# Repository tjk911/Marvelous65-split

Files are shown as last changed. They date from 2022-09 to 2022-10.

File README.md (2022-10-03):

# Marvelous65 Split

All the credit goes to [karnadii](https://github.com/karnadii/marvelous65) for his initial work. This repo is primarily for my documentation purposes and as a guide for anyone that would like to build this but might be as inexperienced as I was when I attempted this. This contains only documentation and updates to the split layout.

Shoutout to [karnadii](https://github.com/karnadii), [Nicell](https://github.com/nicell), bravekarma and the other zmk and nice!nano discord folks that helped me get as far as I did.

## Differences from karnadii's original

I'm running nice!nano on my build instead of nrfmicro. 

If you're buildings his other layouts (marvelous65 and marvelous65-ergo), some of my changes might work there as well. YMMV.

- added nice_nano_v2.overlay, with changes to the mosi-pin
- added oled changes to marvelous_split.dtsi, a zmk change implemented [here](https://zmk.dev/blog/2022/04/02/zephyr-3-0#display-selection)
- updated marvelous65_split.dtsi to reverse flipped encoder

## Known issues
- [OLED issue](https://github.com/zmkfirmware/zmk/issues/674)
- [Split peripheral encoder](https://github.com/zmkfirmware/zmk/pull/728)
  - I pulled [infused-tree](https://github.com/infused-kim/zmk/tree/my-changes/split-encoder)'s changes pending it getting merged into ZMK. So far working OK as of 9/30/22.
- Case does not have access to reset button, or on/off switch toggle
- Seeming to have some lag between the left and the right side in terms of input, I type at a range of 90-130WPM depending on the day but I'm not sure if it's apparent for folks that type slower

## 1. Ordering your PCB

Much like his original repo - you'll have to order these PCBs off of a site like JLCPCB (reach out to me as I might have a few extras lying around). 

You can upload the Gerbers I included to JLCPCB (`Hardware/Gerbers/Gerbers.zip`) or generate them yourself from the Kicad project file.

Options I chose, many of them are default, but I'm including them here for anyone that might find it useful:
- Base material: FR-4
- Layers: 2
- Dimensions: 345.28 * 107.17 (this should be default)
- Panel Qty: 5 (this is the minimum)
- Product Type: Industrial/Consumer electronics
- Different design: 2 
  - This defaults to 1 but it's 2 as they're two separate boards
- Delivery Format: Panel by Customer
- PCB Thickness: 1.6
- PCB Color: Hey, you do you
- Silkscreen: White
- Silkscreen Technology: Ink-jet/Screen Printing Silkscreen
- Sufrace Finish: LeadFree HASL
- Outer Copper Weight: 1 oz
- Gold Fingers: No
- Confirm Production file: Yes
- Flying Probe Test: Fully Test
- Castellated Holes: No
- Remove Order Number: No

### PCB Assembly options

- PCBA Type: Standard
- Assembly Side: Both Sides 
  - I believe you only need the Bottom, but I opted not to risk it during my first build
- PCBA Qty: 5
- Edge Rails/Fiducials: Added by JLCPCB
- Confirm Parts Placement: Yes

After this, you'll need to upload a BOM file and a CPL file. These are `Marvelous65 Split-bom.csv` and `Marvelous65 Split-all-pos.csv` respectively.

You might have to confirm/review the parts. I've noticed that the LED (WS2812B) and the 3.5mm audio jack (PJ-320D) tends to fail to match. Do a search for it and select the appropriate one.

Double check your PCB, I had to rotate the headphone jack to be vertical.

Boom - you're good to go. Pay the good folks and while you're waiting impatiently for your PCBs, get ready to do more shopping.

## 2. Other things you're going to need

I'm assuming you already have a soldering kit etc. Note that while I'll link to the shop pages I bought from - there are no affiliate links whatsoever and I have **no** relationships with these stores. Feel free to shop around and get what serves you best.

For this keyboard specifically, you'll need at least:
- 2x [nice!nano v2s](https://typeractive.xyz/products/nice-nano)
- 2x Lithium batteries
  - You can go big(ger) and grab the [750mAh](https://typeractive.xyz/products/lithium-battery-750mah) batteries or the slimmer [110mAh](https://typeractive.xyz/products/lithium-battery-110mah) versions. 
  - I've heard tell that you can tuck the 110mAh batteries under the nice!nano itself, which might be nice if you're looking for a neat, compact internal
  - I opted for ones with JST sockets
- 2x [Machine sockets and pins](https://typeractive.xyz/products/nice-nano)
  - Technically a nice-to-have but this saved me from a screwup, and it's helpful to be able to unplug the board for troubleshooting
- 2x [128x32 OLED](https://smile.amazon.com/dp/B08ZY4YBHL)
  - Note: ZMK seems to have an [OLED issue](https://github.com/zmkfirmware/zmk/issues/674)
- 2x rotary encoder and knob
- 2x USB-C cables
  - You could just cut up USB-C cables you have and solder one end to the board and plug the other into your nice!nano, but note that the clearance for the nice!nano USB-C and the reset button etc is very slim
  - I opted for some [USB 2.0 cable](https://cruzctrl.gg/collections/diy-cable-parts/products/cable) along with some [USB-C 2.0 connectors](https://cruzctrl.gg/collections/diy-cable-parts/products/usb-c-2-0-connector)
- Case for the keyboard
  - I'm having mine printed from [craftcloud3d](https://craftcloud3d.com/), and they provided me with a 10% referral code: `REF49BRI7SK`
  - The .stl files worked better in my case, and a full PLA build cost about $50-60
- **Optional**
  - Elegoo wire jumper cables
    - I'm soldering these for RGB lighting in order to retain removability - female on nice!nano and male on the PCB
  - If you're building the case included in the repo:
    - M2*5mm
      - You'll need at least eight of these for each corner of the case
    - M2 screws
      - 4x 12mm for the front
      - 4x 20mm to 24mm for the rear corners
        - I'm using 4x20mm but I'd recommend getting 22mm to be safe, it's barely grabbing the top case at all

## 3. Firmware/Software

You have two options here. 

### Use included files
Once built, you could simply rename the `marvelous65_split_left.uf2` and `marvelous65_split_right.uf2` to `zmk.uf2` files, and drop them into your left/right nice!nano board once it's connected to your machine as a USB device. 

### Build your own
If you're looking to make changes to the keymaps etc, I followed [zmk's development setup instructions](https://zmk.dev/docs/development/setup) and [zephyr's installation guide](https://docs.zephyrproject.org/latest/develop/getting_started/index.html) as well. 

After that's done, you can copy/paste the files in the `Firmware\marvelous65_split` folder into `zmk/app/boards/shields/marvelous65_split`. 

In your terminal, you can generate both left/right files at the same time with this command:

```
west build -d build/right -p -b nice_nano_v2 -- -DSHIELD=marvelous65_split_right && west build -d build/left -p -b nice_nano_v2 -- -DSHIELD=marvelous65_split_left
```

If you run into Zephyr build issues after installing zmk and zephy, make sure you have this in your .src file (bashrc or zshrc)
``````
export ZEPHYR_TOOLCHAIN_VARIANT=gnuarmemb
export GNUARMEMB_TOOLCHAIN_PATH=$(brew --prefix) 
``````

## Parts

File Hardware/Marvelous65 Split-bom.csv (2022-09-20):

Comment | Designator | Footprint | LCSC
0.1uF | C1,C2,C3,C4,C5,C6,C7,C8,C9,C10,C11,C12,C13,C14,C15,C16,C17,C18 | Capacitor_SMD:C_0805_2012Metric_Pad1.15x1.40mm_HandSolder | C49678
D | D1,D2,D3,D4,D5,D6,D7,D8,D9,D10,D11,D12,D13,D14,D15,D16,D17,D18,D19,D20,D21,D22,D23,D24,D25,D26,D27,D28,D29,D32,D33,D34,D35,D36,D37,D38,D39,D40,D46,D47,D48,D49,D50,D51,D52,D53,D54,D55,D56,D59,D60,D61,D62,D63,D64,D65,D66,D67,D68,D69,D70,D71,D72,D75,D76,D77,D78,D79,D80,D81 | Diode_SMD:D_SOD-123 | C81598
WS2812B | D30,D31,D41,D42,D43,D44,D45,D57,D58,D73,D74,D82,D83,D84 | LED_SMD:LED_WS2812B_PLCC4_5.0x5.0mm_P3.2mm
MX-NoLED | ISO_ENTER1 | MX_Only:MXOnly-ISO-ROTATED-ReversedStabilizers-NoLED
USB_C_Receptacle_USB2.0 | J1,J5 | Connector_USB:USB_C_Receptacle_HRO_TYPE-C-31-M-12 | C165948
Conn_01x04 | J2,J6 | Connector_PinSocket_2.54mm:PinSocket_1x04_P2.54mm_Vertical
AudioJack4 | J3,J7 | Connector_Audio:Jack_3.5mm_PJ320D_Horizontal | C15139
Conn_01x02 | J4,J8 | Connector_JST:JST_XH_S2B-XH-A_1x02_P2.50mm_Horizontal | C157931
Jumper_2_Bridged | JP1,JP2,JP3,JP4 | SofleKeyboard-footprint:Jumper
1.5 | K_BACKSLASH1,K_CTRL1,K_ALT1,K_TAB1 | MX_Only:MXOnly-1.5U-NoLED
2 | K_BSPC1 | MX_Only:MXOnly-2U-NoLED
2.25 | K_ENTER1,K_LSHIFT1 | MX_Only:MXOnly-2.25U-NoLED
MX-NoLED | K_FN2 | MX_Only:MXOnly-1.25U-NoLED
MX-NoLED | K_NUM0,K_MINUS1,K_EQUAL1,K_O1,K_P1,K_L_PAR1,K_R_PAR1,K_ENC1,K_DEL1,K_I1,K_U1,K_Y1,K_H1,K_J1,K_K1,K_L1,K_DOT1,K_SLASH1,K_UP1,K_QUOTE1,K_COLON1,K_COMMA1,K_M1,K_N1,K_FN1,K_RIGHT1,K_DOWN1,K_LEFT1,ISO_KEY1,L_ENC1,K_GRAVE1,K_NUM1,K_Q1,K_W1,K_E1,K_R1,K_T1,K_A1,K_S1,K_D1,K_F1,K_G1,K_ISO_K1,K_Z1,K_X1,K_C1,K_V1,K_B1,K_ALT2,K_CTRL2,K_BSPC2,K_NUM2,K_NUM3,K_NUM4,K_NUM5,K_NUM6,K_NUM7,K_NUM8,K_NUM9 | MX_Only:MXOnly-1U-NoLED
1.75 | K_RSHIFT1,K_CAPS1 | MX_Only:MXOnly-1.75U-NoLED
1.25 | K_SHIFT_ISO1,K_WIN1,K_CAPS_STEP1,K_CTRL3,K_ALT3 | MX_Only:MXOnly-1.25U-NoLED
2.75 | K_SPACE1 | MX_Only:MXOnly-2.75U-ReversedStabilizers-NoLED
2.25 | K_SPACE2 | MX_Only:MXOnly-2.25U-ReversedStabilizers-NoLED
OLED | OL1,OL2 | kbd:OLED
5.1K | R1,R2,R7,R8 | Resistor_SMD:R_0603_1608Metric_Pad1.05x0.95mm_HandSolder | C23186
10k | R3,R4,R5,R6,R9,R10,R11,R12 | Resistor_SMD:R_0603_1608Metric_Pad1.05x0.95mm_HandSolder | C25804
SW_DPDT_x2 | SW1,SW6 | Button_Switch_SMD:SW_SPDT_PCM12 | C221841
SW_PUSH | SW2,SW4 | Button_Switch_SMD:SW_SPST_TL3342 | C318884
Rotary_Encoder_Switch | SW3,SW5 | Rotary_Encoder:RotaryEncoder_Alps_EC11E-Switch_Vertical_H20mm | C470748
TestPoint | TP1,TP2 | TestPoint:TestPoint_THTPad_D2.5mm_Drill1.2mm
ProMicro | U1,U3 | kbd:ProMicro_v3
USBLC6-2SC6 | U2,U4 | Package_TO_SOT_SMD:SOT-23-6 | C558442

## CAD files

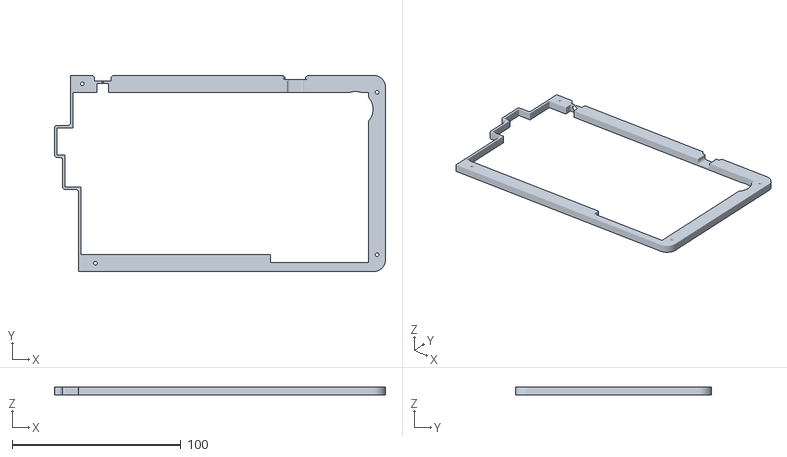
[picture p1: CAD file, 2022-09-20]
Case/Right middle case.stl
196.2 x 116.2 x 5.00

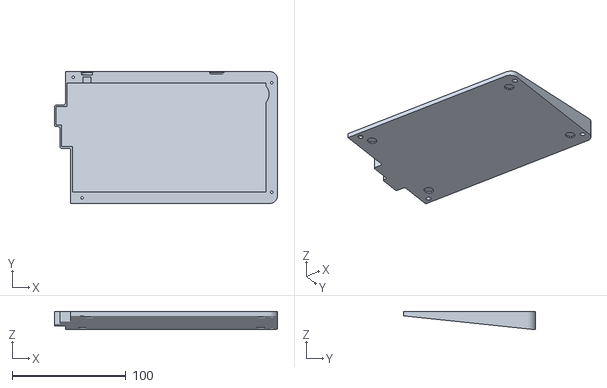
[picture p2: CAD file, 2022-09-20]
Case/Right bottom case.stl
196.2 x 116.2 x 16.2

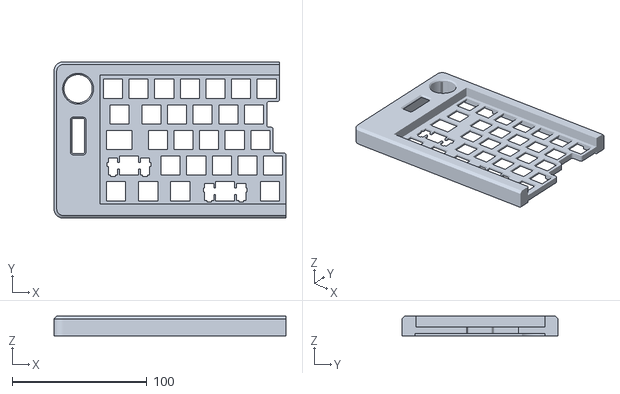
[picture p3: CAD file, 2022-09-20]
Case/Left top case.stl
172.4 x 116.3 x 14.6

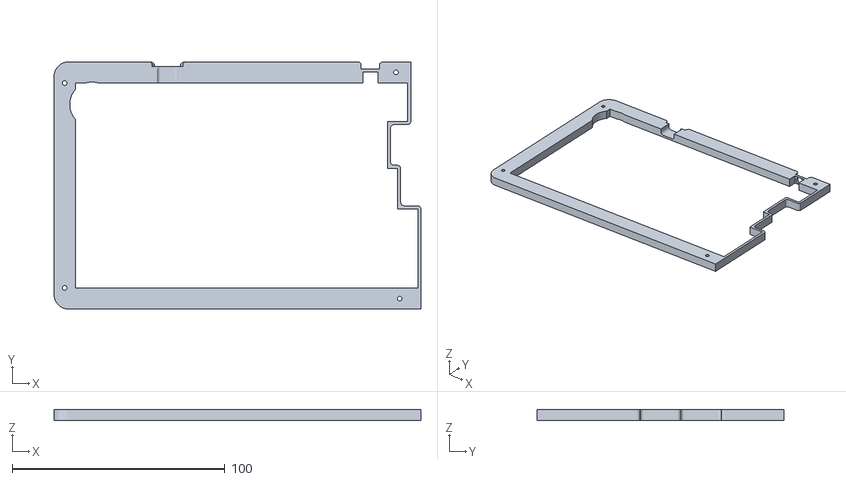
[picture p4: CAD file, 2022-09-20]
Case/Left middle case.stl
172.4 x 116.3 x 5.00

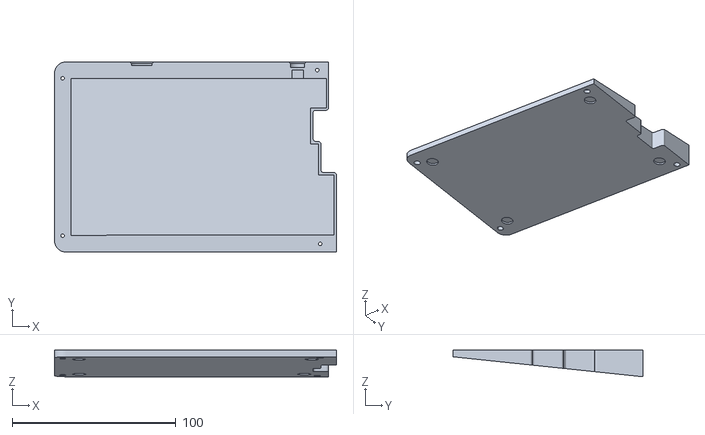
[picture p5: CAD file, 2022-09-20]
Case/Left bottom case.stl
172.4 x 116.3 x 16.2

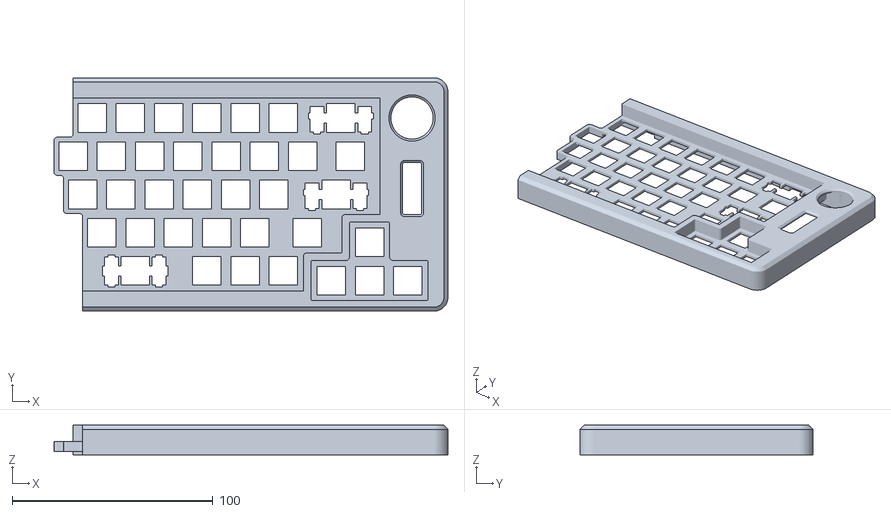
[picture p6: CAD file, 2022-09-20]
Case/Right top case.stl
196.2 x 116.2 x 14.7

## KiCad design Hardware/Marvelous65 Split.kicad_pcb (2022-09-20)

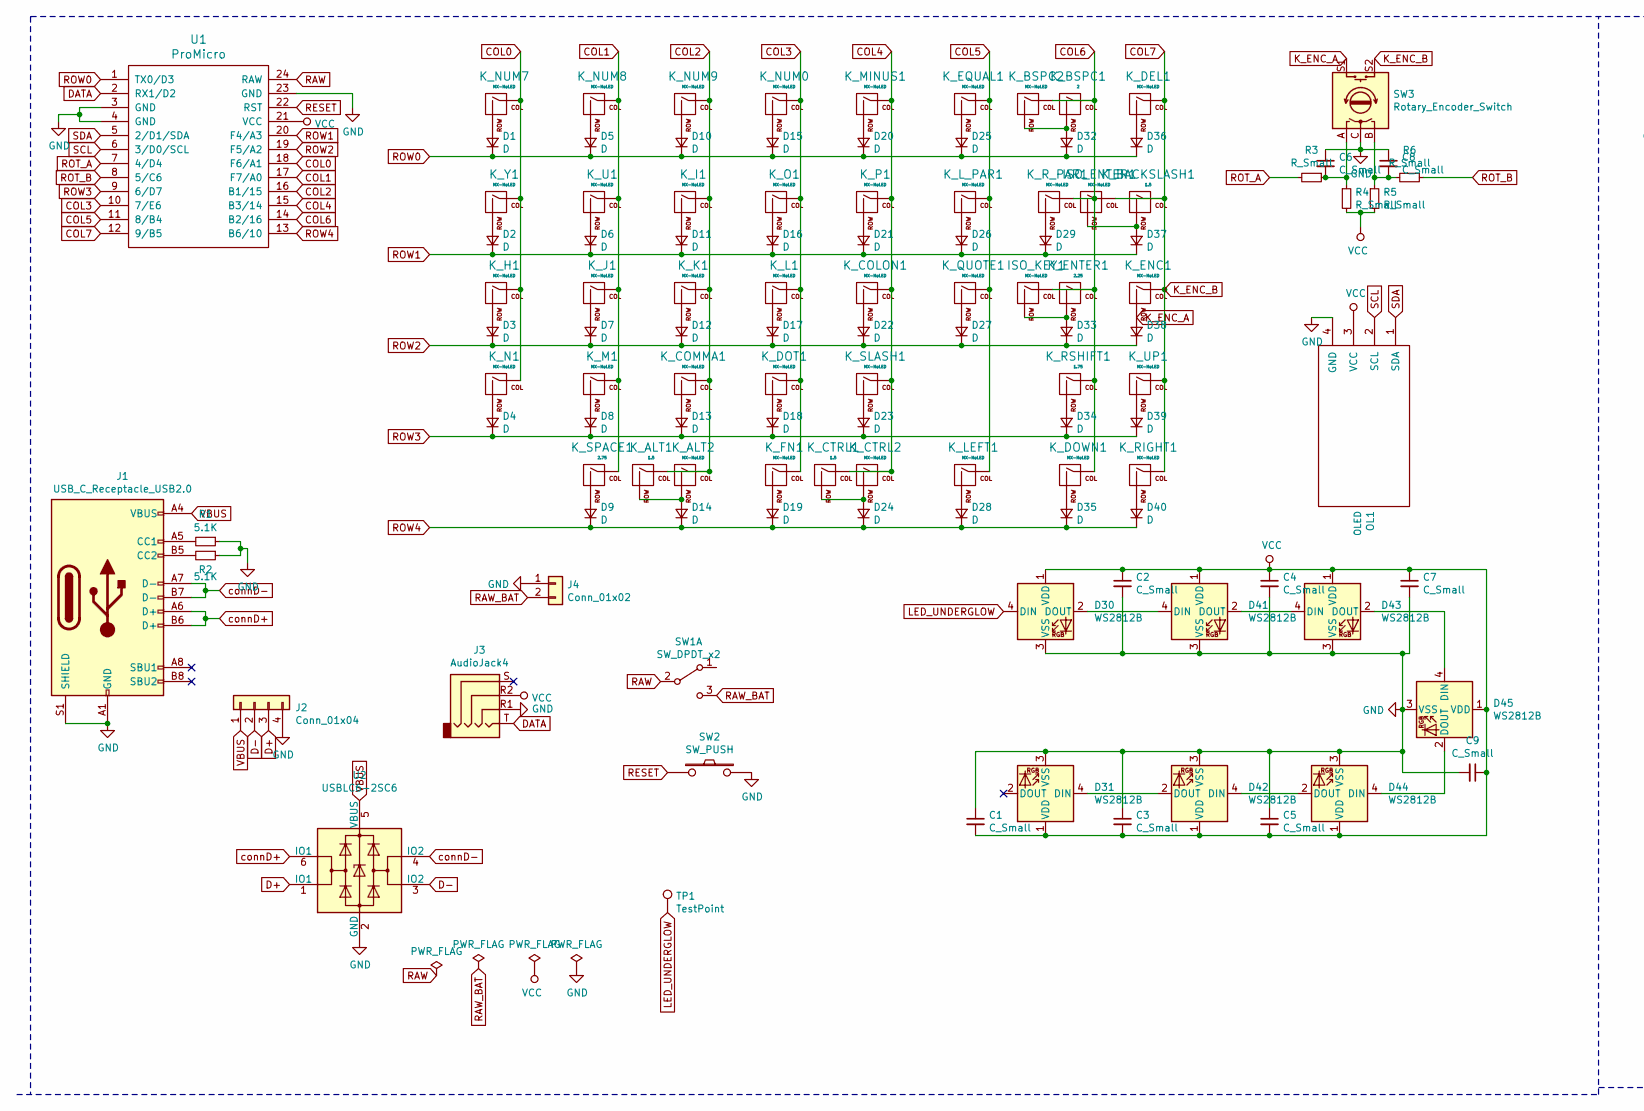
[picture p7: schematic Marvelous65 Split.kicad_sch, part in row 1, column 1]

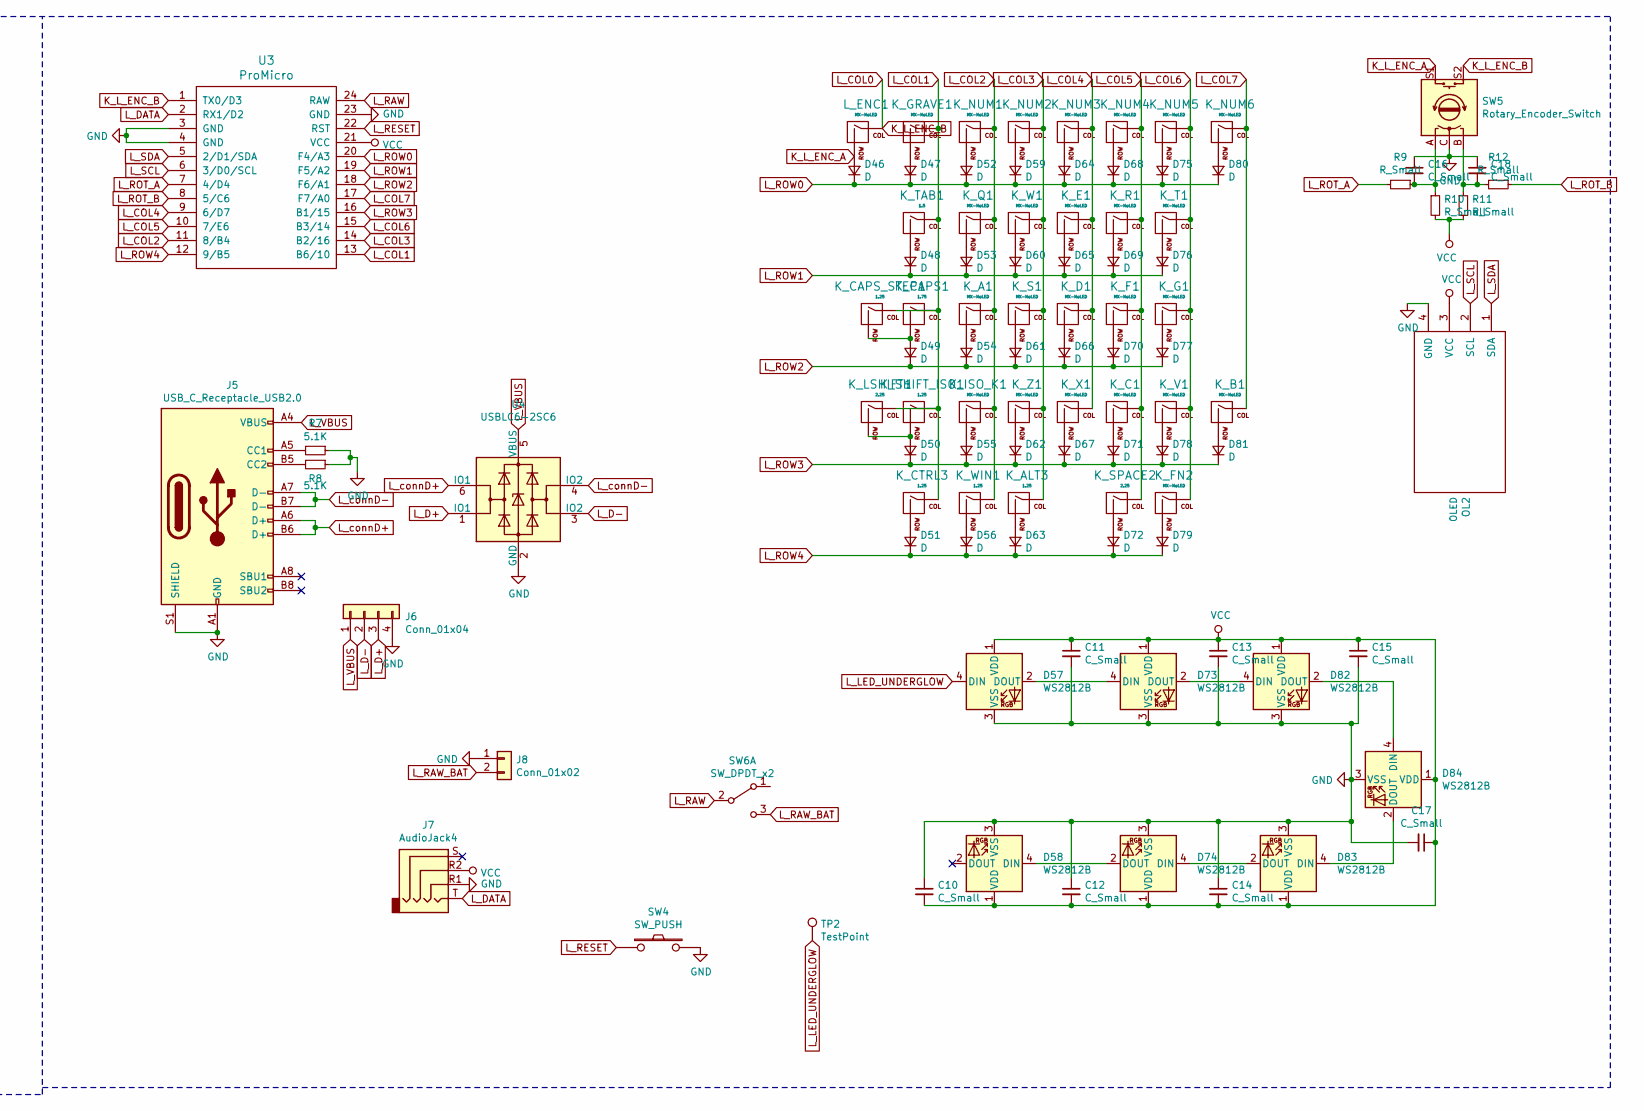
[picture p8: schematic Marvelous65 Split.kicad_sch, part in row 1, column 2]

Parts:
C1, C2, C3, C4, C5, C6, C7, C8, C9, C10, C11, C12, C13, C14, C15, C16, C17, C18: C_Small; C_0805_2012Metric_Pad1.15x1.40mm_HandSolder
D1, D2, D3, D4, D5, D6, D7, D8, D9, D10, D11, D12, D13, D14, D15, D16, D17, D18, D19, D20, D21, D22, D23, D24, D25, D26, D27, D28, D29, D32, D33, D34, D35, D36, D37, D38, D39, D40, D46, D47, D48, D49, D50, D51, D52, D53, D54, D55, D56, D59, D60, D61, D62, D63, D64, D65, D66, D67, D68, D69, D70, D71, D72, D75, D76, D77, D78, D79, D80, D81: D; D_SOD-123
D30, D31, D41, D42, D43, D44, D45, D57, D58, D73, D74, D82, D83, D84: WS2812B; LED_WS2812B_PLCC4_5.0x5.0mm_P3.2mm
ISO_ENTER1: MX-NoLED; MXOnly-ISO-ROTATED-ReversedStabilizers-NoLED
ISO_KEY1: MX-NoLED; MXOnly-1U-NoLED
J1, J5: USB_C_Receptacle_USB2.0; USB_C_Receptacle_HRO_TYPE-C-31-M-12
J2, J6: Conn_01x04; PinSocket_1x04_P2.54mm_Vertical
J3, J7: AudioJack4; Jack_3.5mm_PJ320D_Horizontal
J4, J8: Conn_01x02; JST_XH_S2B-XH-A_1x02_P2.50mm_Horizontal
K_A1: MX-NoLED; MXOnly-1U-NoLED
K_ALT1: 1.5; MXOnly-1.5U-NoLED
K_ALT2: MX-NoLED; MXOnly-1U-NoLED
K_ALT3: 1.25; MXOnly-1.25U-NoLED
K_B1: MX-NoLED; MXOnly-1U-NoLED
K_BACKSLASH1: 1.5; MXOnly-1.5U-NoLED
K_BSPC1: 2; MXOnly-2U-NoLED
K_BSPC2: MX-NoLED; MXOnly-1U-NoLED
K_C1: MX-NoLED; MXOnly-1U-NoLED
K_CAPS1: 1.75; MXOnly-1.75U-NoLED
K_CAPS_STEP1: 1.25; MXOnly-1.25U-NoLED
K_COLON1: MX-NoLED; MXOnly-1U-NoLED
K_COMMA1: MX-NoLED; MXOnly-1U-NoLED
K_CTRL1: 1.5; MXOnly-1.5U-NoLED
K_CTRL2: MX-NoLED; MXOnly-1U-NoLED
K_CTRL3: 1.25; MXOnly-1.25U-NoLED
K_D1: MX-NoLED; MXOnly-1U-NoLED
K_DEL1: MX-NoLED; MXOnly-1U-NoLED
K_DOT1: MX-NoLED; MXOnly-1U-NoLED
K_DOWN1: MX-NoLED; MXOnly-1U-NoLED
K_E1: MX-NoLED; MXOnly-1U-NoLED
K_ENC1: MX-NoLED; MXOnly-1U-NoLED
K_ENTER1: 2.25; MXOnly-2.25U-NoLED
K_EQUAL1: MX-NoLED; MXOnly-1U-NoLED
K_F1: MX-NoLED; MXOnly-1U-NoLED
K_FN1: MX-NoLED; MXOnly-1U-NoLED
K_FN2: MX-NoLED; MXOnly-1.25U-NoLED
K_G1: MX-NoLED; MXOnly-1U-NoLED
K_GRAVE1: MX-NoLED; MXOnly-1U-NoLED
K_H1: MX-NoLED; MXOnly-1U-NoLED
K_I1: MX-NoLED; MXOnly-1U-NoLED
K_ISO_K1: MX-NoLED; MXOnly-1U-NoLED
K_J1: MX-NoLED; MXOnly-1U-NoLED
K_K1: MX-NoLED; MXOnly-1U-NoLED
K_L1: MX-NoLED; MXOnly-1U-NoLED
K_LEFT1: MX-NoLED; MXOnly-1U-NoLED
K_LSHIFT1: 2.25; MXOnly-2.25U-NoLED
K_L_PAR1: MX-NoLED; MXOnly-1U-NoLED
K_M1: MX-NoLED; MXOnly-1U-NoLED
K_MINUS1: MX-NoLED; MXOnly-1U-NoLED
K_N1: MX-NoLED; MXOnly-1U-NoLED
K_NUM0, K_NUM1, K_NUM2, K_NUM3, K_NUM4, K_NUM5, K_NUM6, K_NUM7, K_NUM8, K_NUM9: MX-NoLED; MXOnly-1U-NoLED
K_O1: MX-NoLED; MXOnly-1U-NoLED
K_P1: MX-NoLED; MXOnly-1U-NoLED
K_Q1: MX-NoLED; MXOnly-1U-NoLED
K_QUOTE1: MX-NoLED; MXOnly-1U-NoLED
K_R1: MX-NoLED; MXOnly-1U-NoLED
K_RIGHT1: MX-NoLED; MXOnly-1U-NoLED
K_RSHIFT1: 1.75; MXOnly-1.75U-NoLED
K_R_PAR1: MX-NoLED; MXOnly-1U-NoLED
K_S1: MX-NoLED; MXOnly-1U-NoLED
K_SHIFT_ISO1: 1.25; MXOnly-1.25U-NoLED
K_SLASH1: MX-NoLED; MXOnly-1U-NoLED
K_SPACE1: 2.75; MXOnly-2.75U-ReversedStabilizers-NoLED
K_SPACE2: 2.25; MXOnly-2.25U-ReversedStabilizers-NoLED
K_T1: MX-NoLED; MXOnly-1U-NoLED
K_TAB1: 1.5; MXOnly-1.5U-NoLED
K_U1: MX-NoLED; MXOnly-1U-NoLED
K_UP1: MX-NoLED; MXOnly-1U-NoLED
K_V1: MX-NoLED; MXOnly-1U-NoLED
K_W1: MX-NoLED; MXOnly-1U-NoLED
K_WIN1: 1.25; MXOnly-1.25U-NoLED
K_X1: MX-NoLED; MXOnly-1U-NoLED
K_Y1: MX-NoLED; MXOnly-1U-NoLED
K_Z1: MX-NoLED; MXOnly-1U-NoLED
L_ENC1: MX-NoLED; MXOnly-1U-NoLED
OL1, OL2: OLED
R1, R2, R7, R8: 5.1K; R_0603_1608Metric_Pad1.05x0.95mm_HandSolder
R3, R4, R5, R6, R9, R10, R11, R12: R_Small; R_0603_1608Metric_Pad1.05x0.95mm_HandSolder
SW1, SW6: SW_DPDT_x2; SW_SPDT_PCM12
SW2, SW4: SW_PUSH; SW_SPST_TL3342
SW3, SW5: Rotary_Encoder_Switch; RotaryEncoder_Alps_EC11E-Switch_Vertical_H20mm
TP1, TP2: TestPoint; TestPoint_THTPad_D2.5mm_Drill1.2mm
U1, U3: ProMicro; ProMicro_v3
U2, U4: USBLC6-2SC6; SOT-23-6

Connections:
COL0: K_H1.1 (COL), K_N1.1 (COL), K_NUM7.1 (COL), K_Y1.1 (COL), U1.18 (F6/A1)
COL1: K_J1.1 (COL), K_M1.1 (COL), K_NUM8.1 (COL), K_SPACE1.1 (COL), K_U1.1 (COL), U1.17 (F7/A0)
COL2: K_ALT1.1 (COL), K_ALT2.1 (COL), K_COMMA1.1 (COL), K_I1.1 (COL), K_K1.1 (COL), K_NUM9.1 (COL), U1.16 (B1/15)
COL3: K_DOT1.1 (COL), K_FN1.1 (COL), K_L1.1 (COL), K_NUM0.1 (COL), K_O1.1 (COL), U1.10 (7/E6)
COL4: K_COLON1.1 (COL), K_CTRL1.1 (COL), K_CTRL2.1 (COL), K_MINUS1.1 (COL), K_P1.1 (COL), K_SLASH1.1 (COL), U1.15 (B3/14)
COL5: K_EQUAL1.1 (COL), K_LEFT1.1 (COL), K_L_PAR1.1 (COL), K_QUOTE1.1 (COL), U1.11 (8/B4)
COL6: ISO_KEY1.1 (COL), K_BSPC1.1 (COL), K_BSPC2.1 (COL), K_DOWN1.1 (COL), K_ENTER1.1 (COL), K_RSHIFT1.1 (COL), K_R_PAR1.1 (COL), U1.14 (B2/16)
COL7: ISO_ENTER1.1 (COL), K_BACKSLASH1.1 (COL), K_DEL1.1 (COL), K_ENC1.1 (COL), K_RIGHT1.1 (COL), K_UP1.1 (COL), SW3.S2, U1.12 (9/B5)
D+: J2.3, U2.1 (IO1)
D-: J2.2, U2.3 (IO2)
DATA: J3.T, U1.2 (RX1/D2)
GND: C1.1, C2.2, C3.1, C4.2, C5.1, C6.1, C7.2, C8.1, C9.2, C10.1, C11.2, C12.1, C13.2, C14.1, C15.2, C16.1, C17.2, C18.1, D30.3 (VSS), D31.3 (VSS), D41.3 (VSS), D42.3 (VSS), D43.3 (VSS), D44.3 (VSS), D45.3 (VSS), D57.3 (VSS), D58.3 (VSS), D73.3 (VSS), D74.3 (VSS), D82.3 (VSS), D83.3 (VSS), D84.3 (VSS), J1.A1 (GND), J1.A12 (GND), J1.B1 (GND), J1.B12 (GND), J1.S1 (SHIELD), J2.4, J3.R1, J4.1, J5.A1 (GND), J5.A12 (GND), J5.B1 (GND), J5.B12 (GND), J5.S1 (SHIELD), J6.4, J7.R1, J8.1, OL1.4 (GND), OL2.4 (GND), R1.1, R2.1, R7.1, R8.1, SW2.2, SW3.C, SW4.2, SW5.C, U1.3 (GND), U1.4 (GND), U1.23 (GND), U2.2 (GND), U3.3 (GND), U3.4 (GND), U3.23 (GND), U4.2 (GND)
K_ENC_A: D38.2 (A), K_ENC1.2 (ROW), SW3.S1
K_L_ENC_A: D46.2 (A), L_ENC1.2 (ROW), SW5.S1
K_L_ENC_B: L_ENC1.1 (COL), SW5.S2, U3.1 (TX0/D3)
LED_UNDERGLOW: D30.4 (DIN), TP1.1
L_COL1: K_CAPS1.1 (COL), K_CAPS_STEP1.1 (COL), K_CTRL3.1 (COL), K_GRAVE1.1 (COL), K_LSHIFT1.1 (COL), K_SHIFT_ISO1.1 (COL), K_TAB1.1 (COL), U3.13 (B6/10)
L_COL2: K_A1.1 (COL), K_ISO_K1.1 (COL), K_NUM1.1 (COL), K_Q1.1 (COL), K_WIN1.1 (COL), U3.11 (8/B4)
L_COL3: K_ALT3.1 (COL), K_NUM2.1 (COL), K_S1.1 (COL), K_W1.1 (COL), K_Z1.1 (COL), U3.14 (B2/16)
L_COL4: K_D1.1 (COL), K_E1.1 (COL), K_NUM3.1 (COL), K_X1.1 (COL), U3.9 (6/D7)
L_COL5: K_C1.1 (COL), K_F1.1 (COL), K_NUM4.1 (COL), K_R1.1 (COL), K_SPACE2.1 (COL), U3.10 (7/E6)
L_COL6: K_FN2.1 (COL), K_G1.1 (COL), K_NUM5.1 (COL), K_T1.1 (COL), K_V1.1 (COL), U3.15 (B3/14)
L_COL7: K_B1.1 (COL), K_NUM6.1 (COL), U3.17 (F7/A0)
L_D+: J6.3, U4.1 (IO1)
L_D-: J6.2, U4.3 (IO2)
L_DATA: J7.T, U3.2 (RX1/D2)
L_LED_UNDERGLOW: D57.4 (DIN), TP2.1
L_RAW: SW6.2 (B), U3.24 (RAW)
L_RAW_BAT: J8.2, SW6.3 (C)
L_RESET: SW4.1, U3.22 (RST)
L_ROTA_A: C16.2, R9.1, R10.1, SW5.A; also elsewhere on the board
L_ROTA_B: C18.2, R11.1, R12.2, SW5.B; also elsewhere on the board
L_ROT_A: R9.2, U3.7 (4/D4); also elsewhere on the board
L_ROT_B: R12.1, U3.8 (5/C6); also elsewhere on the board
L_ROW0: D46.1 (K), D47.1 (K), D52.1 (K), D59.1 (K), D64.1 (K), D68.1 (K), D75.1 (K), D80.1 (K), U3.20 (F4/A3)
L_ROW1: D48.1 (K), D53.1 (K), D60.1 (K), D65.1 (K), D69.1 (K), D76.1 (K), U3.19 (F5/A2)
L_ROW2: D49.1 (K), D54.1 (K), D61.1 (K), D66.1 (K), D70.1 (K), D77.1 (K), U3.18 (F6/A1)
L_ROW3: D50.1 (K), D55.1 (K), D62.1 (K), D67.1 (K), D71.1 (K), D78.1 (K), D81.1 (K), U3.16 (B1/15)
L_ROW4: D51.1 (K), D56.1 (K), D63.1 (K), D72.1 (K), D79.1 (K), U3.12 (9/B5)
L_SCL: OL2.2 (SCL), U3.6 (3/D0/SCL)
L_SDA: OL2.1 (SDA), U3.5 (2/D1/SDA)
L_VBUS: J5.A4 (VBUS), J5.A9 (VBUS), J5.B4 (VBUS), J5.B9 (VBUS), J6.1, U4.5 (VBUS)
L_connD+: J5.A6 (D+), J5.B6 (D+), U4.6 (IO1)
L_connD-: J5.A7 (D-), J5.B7 (D-), U4.4 (IO2)
unnamed: D1.2 (A), K_NUM7.2 (ROW)
unnamed: D2.2 (A), K_Y1.2 (ROW)
unnamed: D3.2 (A), K_H1.2 (ROW)
unnamed: D4.2 (A), K_N1.2 (ROW)
unnamed: D5.2 (A), K_NUM8.2 (ROW)
unnamed: D6.2 (A), K_U1.2 (ROW)
unnamed: D7.2 (A), K_J1.2 (ROW)
unnamed: D8.2 (A), K_M1.2 (ROW)
unnamed: D9.2 (A), K_SPACE1.2 (ROW)
unnamed: D10.2 (A), K_NUM9.2 (ROW)
unnamed: D11.2 (A), K_I1.2 (ROW)
unnamed: D12.2 (A), K_K1.2 (ROW)
unnamed: D13.2 (A), K_COMMA1.2 (ROW)
unnamed: D14.2 (A), K_ALT1.2 (ROW), K_ALT2.2 (ROW)
unnamed: D15.2 (A), K_NUM0.2 (ROW)
unnamed: D16.2 (A), K_O1.2 (ROW)
unnamed: D17.2 (A), K_L1.2 (ROW)
unnamed: D18.2 (A), K_DOT1.2 (ROW)
unnamed: D19.2 (A), K_FN1.2 (ROW)
unnamed: D20.2 (A), K_MINUS1.2 (ROW)
unnamed: D21.2 (A), K_P1.2 (ROW)
unnamed: D22.2 (A), K_COLON1.2 (ROW)
unnamed: D23.2 (A), K_SLASH1.2 (ROW)
unnamed: D24.2 (A), K_CTRL1.2 (ROW), K_CTRL2.2 (ROW)
unnamed: D25.2 (A), K_EQUAL1.2 (ROW)
unnamed: D26.2 (A), K_L_PAR1.2 (ROW)
unnamed: D27.2 (A), K_QUOTE1.2 (ROW)
unnamed: D28.2 (A), K_LEFT1.2 (ROW)
unnamed: D29.2 (A), K_R_PAR1.2 (ROW)
unnamed: D30.2 (DOUT), D41.4 (DIN)
unnamed: D31.4 (DIN), D42.2 (DOUT)
unnamed: D32.2 (A), K_BSPC1.2 (ROW), K_BSPC2.2 (ROW)
unnamed: D33.2 (A), ISO_KEY1.2 (ROW), K_ENTER1.2 (ROW)
unnamed: D34.2 (A), K_RSHIFT1.2 (ROW)
unnamed: D35.2 (A), K_DOWN1.2 (ROW)
unnamed: D36.2 (A), K_DEL1.2 (ROW)
unnamed: D37.2 (A), ISO_ENTER1.2 (ROW), K_BACKSLASH1.2 (ROW)
unnamed: D39.2 (A), K_UP1.2 (ROW)
unnamed: D40.2 (A), K_RIGHT1.2 (ROW)
unnamed: D41.2 (DOUT), D43.4 (DIN)
unnamed: D42.4 (DIN), D44.2 (DOUT)
unnamed: D43.2 (DOUT), D45.4 (DIN)
unnamed: D44.4 (DIN), D45.2 (DOUT)
unnamed: D47.2 (A), K_GRAVE1.2 (ROW)
unnamed: D48.2 (A), K_TAB1.2 (ROW)
unnamed: D49.2 (A), K_CAPS1.2 (ROW), K_CAPS_STEP1.2 (ROW)
unnamed: D50.2 (A), K_LSHIFT1.2 (ROW), K_SHIFT_ISO1.2 (ROW)
unnamed: D51.2 (A), K_CTRL3.2 (ROW)
unnamed: D52.2 (A), K_NUM1.2 (ROW)
unnamed: D53.2 (A), K_Q1.2 (ROW)
unnamed: D54.2 (A), K_A1.2 (ROW)
unnamed: D55.2 (A), K_ISO_K1.2 (ROW)
unnamed: D56.2 (A), K_WIN1.2 (ROW)
unnamed: D57.2 (DOUT), D73.4 (DIN)
unnamed: D58.4 (DIN), D74.2 (DOUT)
unnamed: D59.2 (A), K_NUM2.2 (ROW)
unnamed: D60.2 (A), K_W1.2 (ROW)
unnamed: D61.2 (A), K_S1.2 (ROW)
unnamed: D62.2 (A), K_Z1.2 (ROW)
unnamed: D63.2 (A), K_ALT3.2 (ROW)
unnamed: D64.2 (A), K_NUM3.2 (ROW)
unnamed: D65.2 (A), K_E1.2 (ROW)
unnamed: D66.2 (A), K_D1.2 (ROW)
unnamed: D67.2 (A), K_X1.2 (ROW)
unnamed: D68.2 (A), K_NUM4.2 (ROW)
unnamed: D69.2 (A), K_R1.2 (ROW)
unnamed: D70.2 (A), K_F1.2 (ROW)
unnamed: D71.2 (A), K_C1.2 (ROW)
unnamed: D72.2 (A), K_SPACE2.2 (ROW)
unnamed: D73.2 (DOUT), D82.4 (DIN)
unnamed: D74.4 (DIN), D83.2 (DOUT)
unnamed: D75.2 (A), K_NUM5.2 (ROW)
unnamed: D76.2 (A), K_T1.2 (ROW)
unnamed: D77.2 (A), K_G1.2 (ROW)
unnamed: D78.2 (A), K_V1.2 (ROW)
unnamed: D79.2 (A), K_FN2.2 (ROW)
unnamed: D80.2 (A), K_NUM6.2 (ROW)
unnamed: D81.2 (A), K_B1.2 (ROW)
unnamed: D82.2 (DOUT), D84.4 (DIN)
unnamed: D83.4 (DIN), D84.2 (DOUT)
unnamed: J1.A5 (CC1), R1.2
unnamed: J1.B5 (CC2), R2.2
unnamed: J5.A5 (CC1), R7.2
unnamed: J5.B5 (CC2), R8.2
RAW: SW1.2 (B), U1.24 (RAW)
RAW_BAT: J4.2, SW1.3 (C)
RESET: SW2.1, U1.22 (RST)
ROTA_A: C6.2, R3.1, R4.1, SW3.A; also elsewhere on the board
ROTA_B: C8.2, R5.1, R6.2, SW3.B; also elsewhere on the board
ROT_A: R3.2, U1.7 (4/D4); also elsewhere on the board
ROT_B: R6.1, U1.8 (5/C6); also elsewhere on the board
ROW0: D1.1 (K), D5.1 (K), D10.1 (K), D15.1 (K), D20.1 (K), D25.1 (K), D32.1 (K), D36.1 (K), U1.1 (TX0/D3)
ROW1: D2.1 (K), D6.1 (K), D11.1 (K), D16.1 (K), D21.1 (K), D26.1 (K), D29.1 (K), D37.1 (K), U1.20 (F4/A3)
ROW2: D3.1 (K), D7.1 (K), D12.1 (K), D17.1 (K), D22.1 (K), D27.1 (K), D33.1 (K), D38.1 (K), U1.19 (F5/A2)
ROW3: D4.1 (K), D8.1 (K), D13.1 (K), D18.1 (K), D23.1 (K), D34.1 (K), D39.1 (K), U1.9 (6/D7)
ROW4: D9.1 (K), D14.1 (K), D19.1 (K), D24.1 (K), D28.1 (K), D35.1 (K), D40.1 (K), U1.13 (B6/10)
SCL: OL1.2 (SCL), U1.6 (3/D0/SCL)
SDA: OL1.1 (SDA), U1.5 (2/D1/SDA)
VBUS: J1.A4 (VBUS), J1.A9 (VBUS), J1.B4 (VBUS), J1.B9 (VBUS), J2.1, U2.5 (VBUS)
VCC: C1.2, C2.1, C3.2, C4.1, C5.2, C7.1, C9.1, C10.2, C11.1, C12.2, C13.1, C14.2, C15.1, C17.1, D30.1 (VDD), D31.1 (VDD), D41.1 (VDD), D42.1 (VDD), D43.1 (VDD), D44.1 (VDD), D45.1 (VDD), D57.1 (VDD), D58.1 (VDD), D73.1 (VDD), D74.1 (VDD), D82.1 (VDD), D83.1 (VDD), D84.1 (VDD), J3.R2, J7.R2, OL1.3 (VCC), OL2.3 (VCC), R4.2, R5.2, R10.2, R11.2, U1.21 (VCC), U3.21 (VCC)
connD+: J1.A6 (D+), J1.B6 (D+), U2.6 (IO1)
connD-: J1.A7 (D-), J1.B7 (D-), U2.4 (IO2)

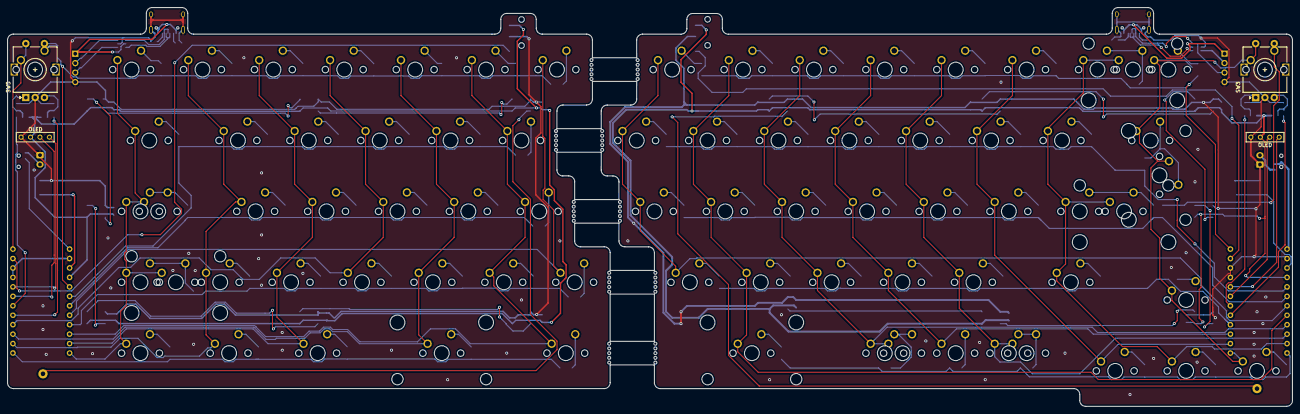
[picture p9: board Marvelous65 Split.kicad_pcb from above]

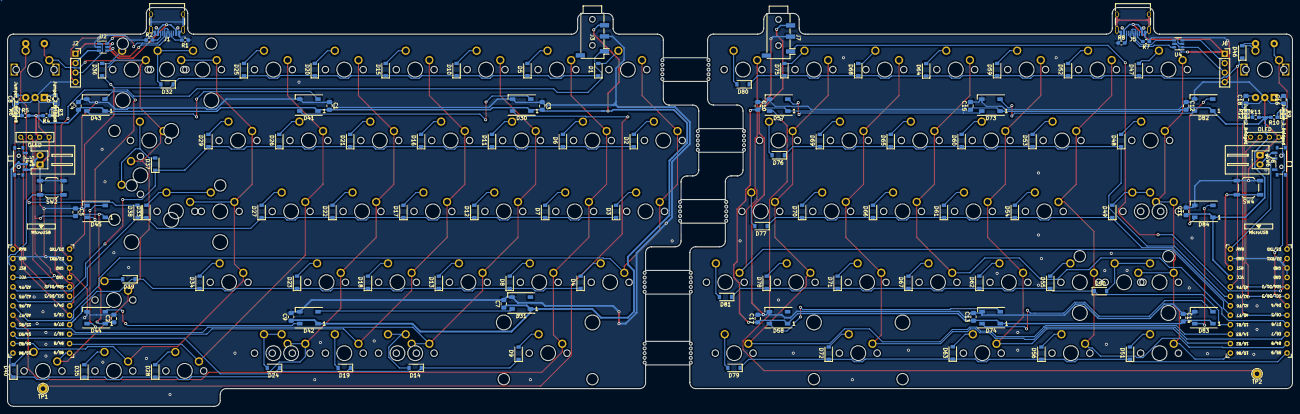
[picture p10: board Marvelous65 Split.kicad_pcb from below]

Board: 2 copper layers, 345.3 x 107.2 mm, 217 parts (137 on the bottom side), 146 nets.

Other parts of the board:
JP1, JP2, JP3, JP4: Jumper_2_Bridged; Jumper

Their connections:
L_ROTA_A: JP3.2; also elsewhere on the board
L_ROTA_B: JP4.2; also elsewhere on the board
L_ROT_A: JP3.1; also elsewhere on the board
L_ROT_B: JP4.1; also elsewhere on the board
ROTA_A: JP2.1; also elsewhere on the board
ROTA_B: JP1.1; also elsewhere on the board
ROT_A: JP2.2; also elsewhere on the board
ROT_B: JP1.2; also elsewhere on the board

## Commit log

2022-09-30 Document split peripheral encoder issue
2022-10-03 Add screw documentation and lag documentation
